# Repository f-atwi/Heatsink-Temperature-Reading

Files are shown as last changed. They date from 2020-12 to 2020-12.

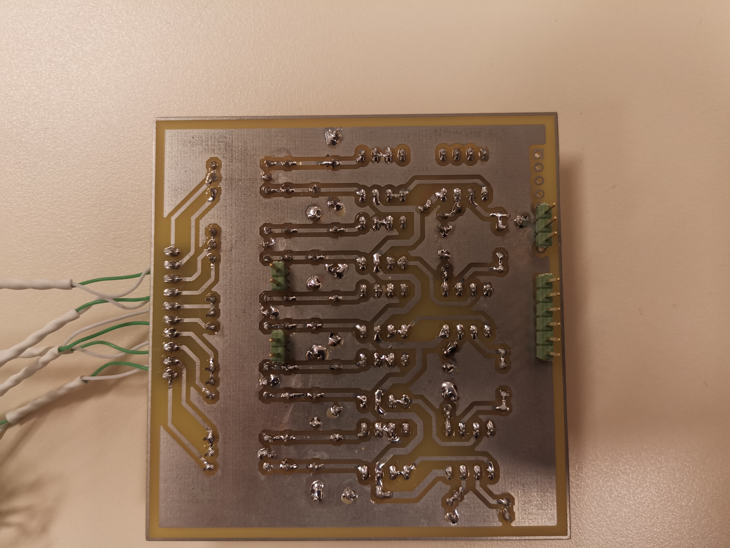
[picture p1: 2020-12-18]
PCB_Bottom.jpg

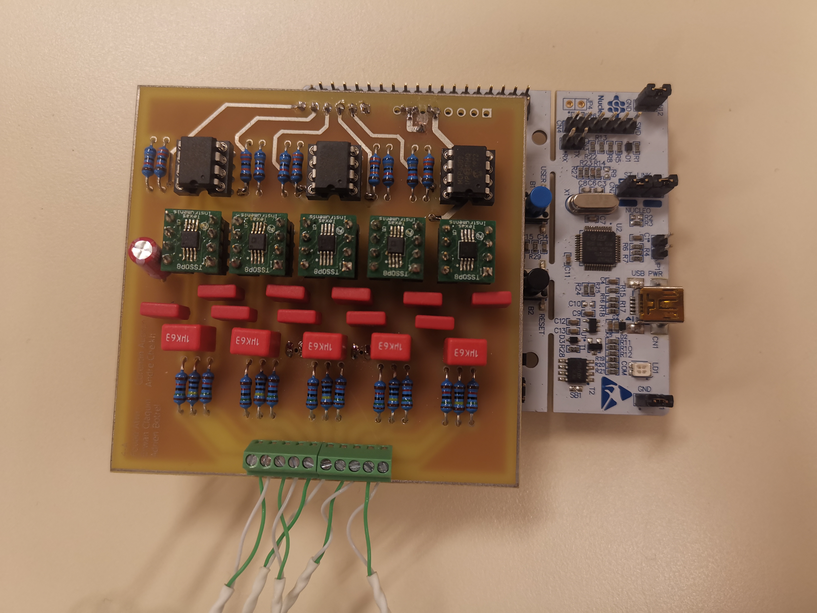
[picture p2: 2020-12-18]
PCB_Top.jpg

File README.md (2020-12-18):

# Heatsink_Temperature_Reading
A project to read temperature of a heatsink by 5 thermocouples and 3D visualize them on the computer.

The PCB design was made completely on Eagle. 
Custom packages for the AD8495 where created to make the board. The board was designed as a shield for the STM32 Nucleo F411RE and also compatible with Arduino boards. 
PDFs of the schematic and board as well as the PCB project files can be found.
The ciruit was designed to be powered completely by the Nucleo board. No external connections required.

The code for the STM32 Nucleo F411RE board was written on the STM32Cube IDE. 
The code initialized an ADC to read data from the designed shield, a DMA to transfer data from ADC to memory, and a UART to tranfer data to the PC.
The data read are also paired with a sensor ID for correct reading on the PC end.

Solidworks was used to model the heatsink. This model will be used by matlab to show temperatures as colors.

The Matlab code is where all the visualizing takes place.
Matlab takes the obj file of the model. 
It uses data received from UART to get the temperatures. The IDs transmitted with the temperatures helps pinpoint which sensor the data is from.
The data is hence displayed as color where blue is the coldest (minimum is 15°C) and red is the hottest (maximum 60°C).

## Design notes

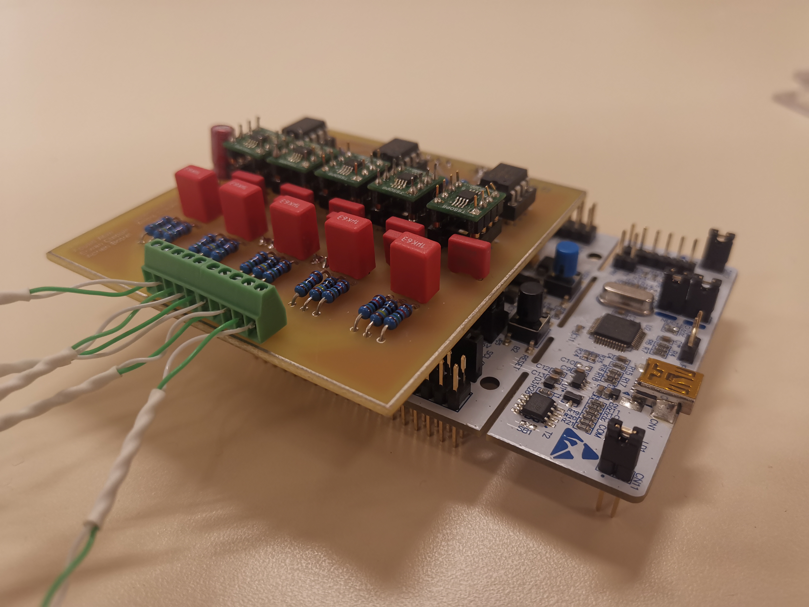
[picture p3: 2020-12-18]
PCB_Top_w_STM32.jpg

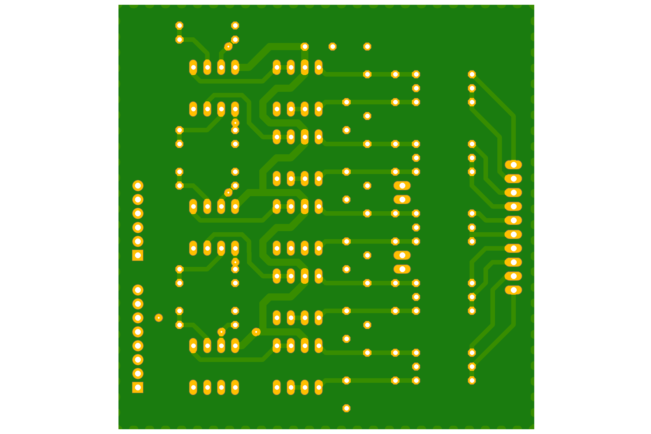
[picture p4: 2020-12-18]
Eagle_PCB_Project/PCB_Bottom_Visualize.png

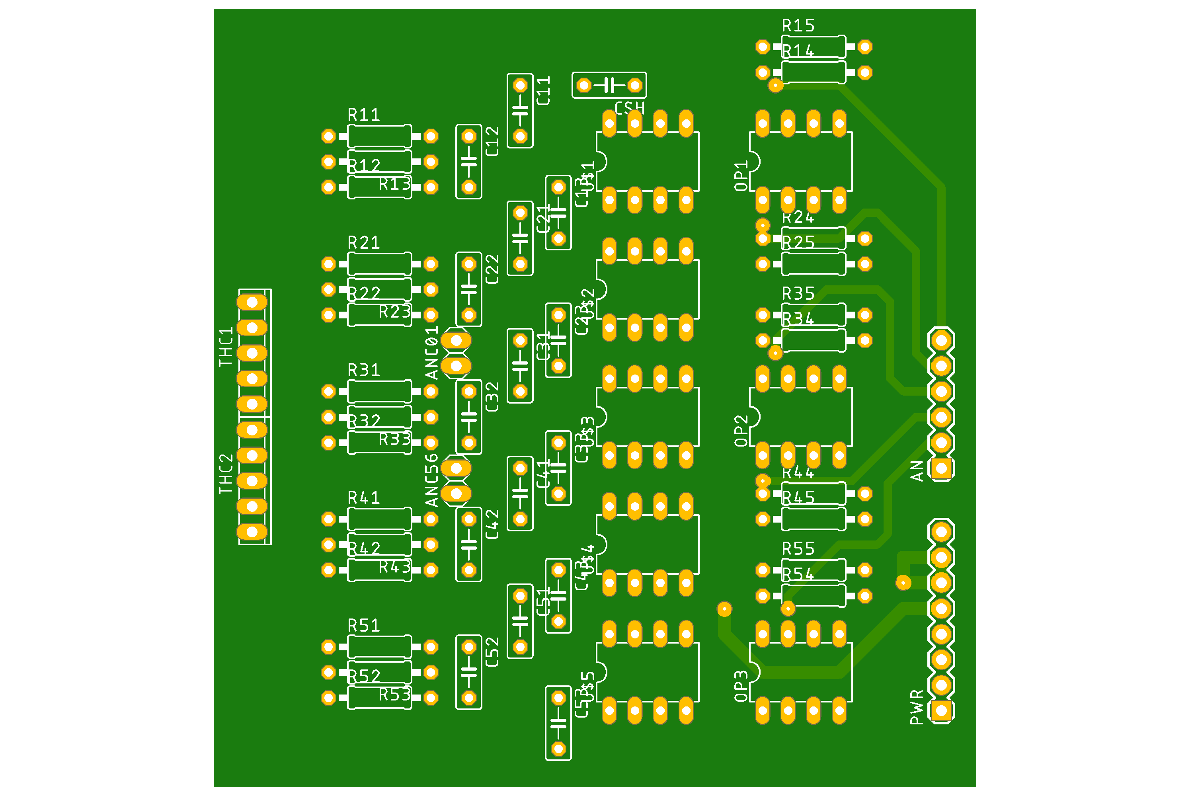
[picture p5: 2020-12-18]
Eagle_PCB_Project/PCB_Top_Visualize.png

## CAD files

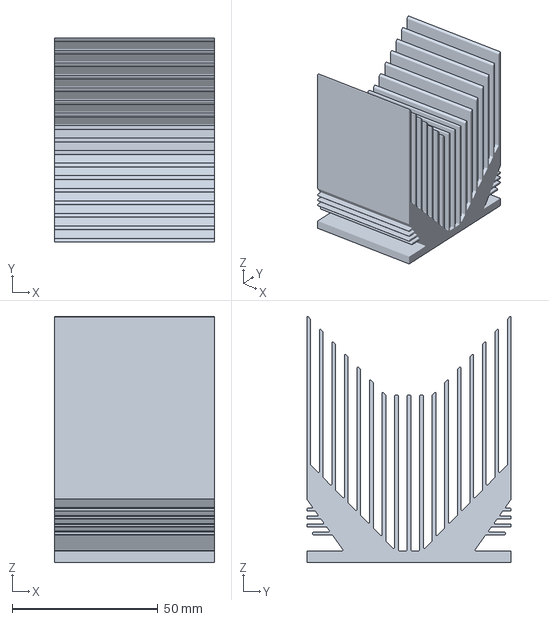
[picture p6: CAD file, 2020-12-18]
3D Model/Heatsink.3MF
55.0 x 70.1 x 84.3 mm

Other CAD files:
3D Model/Heatsink.obj

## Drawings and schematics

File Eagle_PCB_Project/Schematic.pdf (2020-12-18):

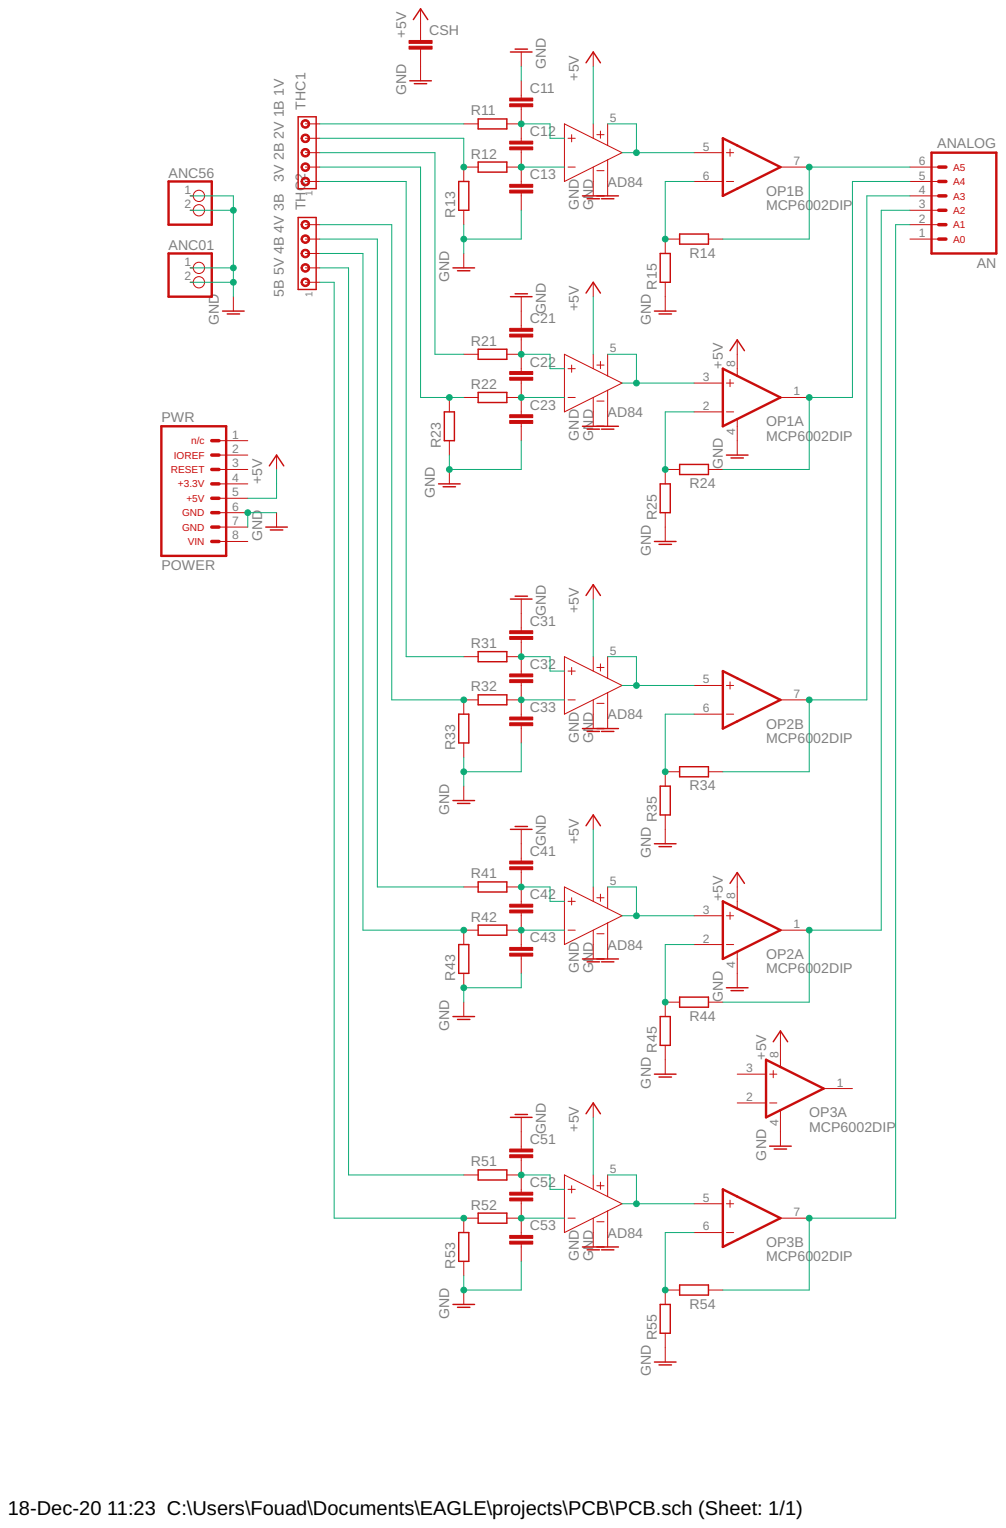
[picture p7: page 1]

GND GND GND GND GND

GND GND GND GND GND GND GND GND GND GND GND GND GND GND GND

18-Dec-20 11:23 C:\Users\Fouad\Documents\EAGLE\projects\PCB\PCB.sch (Sheet: 1/1)

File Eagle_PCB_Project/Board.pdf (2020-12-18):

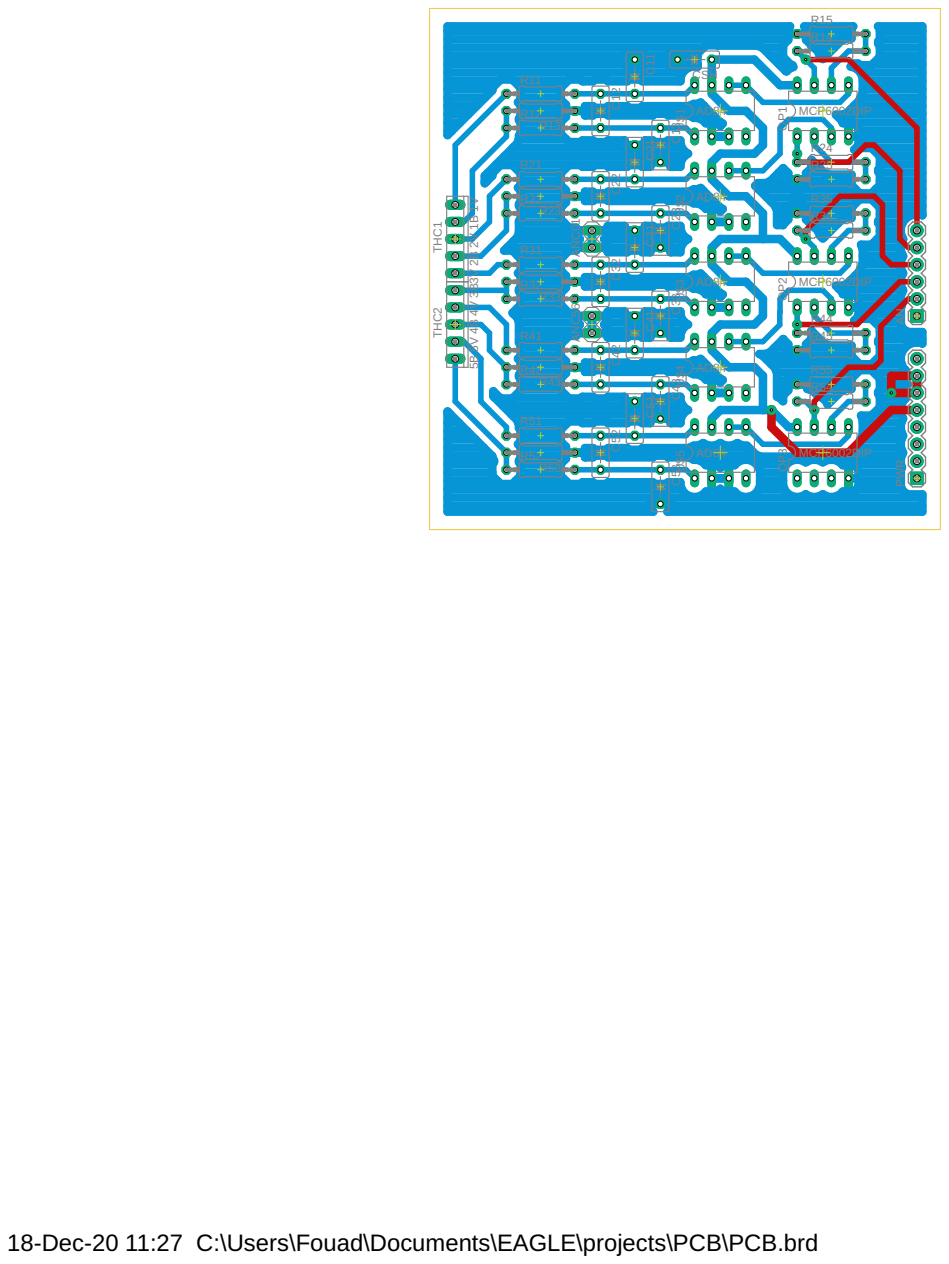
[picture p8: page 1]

18-Dec-20 11:27 C:\Users\Fouad\Documents\EAGLE\projects\PCB\PCB.brd

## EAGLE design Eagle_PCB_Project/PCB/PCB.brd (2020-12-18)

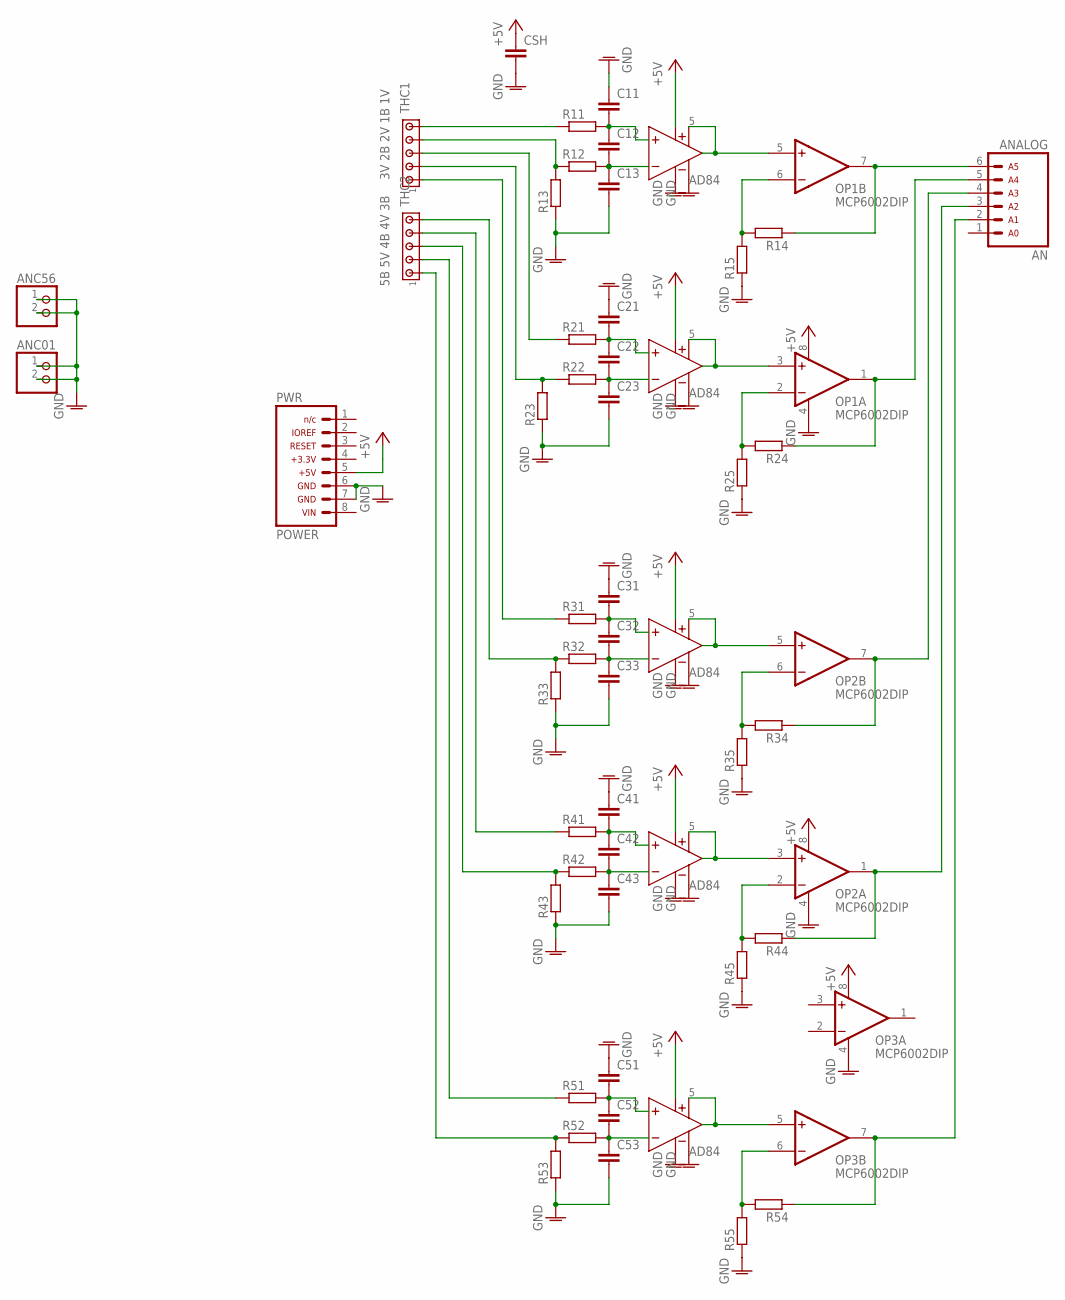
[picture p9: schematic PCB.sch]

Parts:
AN: ARDUINO_CONN-ANALOGSIP; CONN-1X06
ANC01, ANC56: PINHD-1X2; 1X02
C11, C12, C13, C21, C22, C23, C31, C32, C33, C41, C42, C43, C51, C52, C53: C-EU050-025X075; C050-025X075
CSH: C-EU050-025X075; C050-025X075
OP1, OP2, OP3: MCP6002DIP; DIP-8
PWR: ARDUINO_CONN-POWERSIP; CONN-1X08
R11, R12, R13, R14, R15, R21, R22, R23, R24, R25, R31, R32, R33, R34, R35, R41, R42, R43, R44, R45, R51, R52, R53, R54, R55: R-EU_0207/10; 0207/10
THC1: 3V 2B 2V 1B 1V; 10X05MTA
THC2: 5B 5V 4B 4V 3B; 10X05MTA
U$1, U$2, U$3, U$4, U$5: AD84; DIP-8

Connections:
+5V: CSH.1, OP1.8 (V+), OP2.8 (V+), OP3.8 (V+), PWR.5, U$1.7 (V+), U$2.7 (V+), U$3.7 (V+), U$4.7 (V+), U$5.7 (V+)
GNDA: ANC01.1, ANC01.2, ANC56.1, ANC56.2, C11.1, C13.2, C21.1, C23.2, C31.1, C33.2, C41.1, C43.2, C51.1, C53.2, CSH.2, OP1.4 (V-), OP2.4 (V-), OP3.4 (V-), PWR.6, PWR.7, R13.1, R15.1, R23.1, R25.1, R33.1, R35.1, R43.1, R45.1, R53.1, R55.1, U$1.2 (REF), U$1.3 (V-), U$2.2 (REF), U$2.3 (V-), U$3.2 (REF), U$3.3 (V-), U$4.2 (REF), U$4.3 (V-), U$5.2 (REF), U$5.3 (V-)
unnamed: OP1.5 (+IN), U$1.5 (SENS), U$1.6 (OUT)
unnamed: AN.6, OP1.7 (OUT), R14.1
unnamed: OP1.6 (-IN), R14.2, R15.2
unnamed: C11.2, C12.1, R11.2, U$1.8 (IN+)
unnamed: R12.1, R13.2, THC1.4
unnamed: C12.2, C13.1, R12.2, U$1.1 (IN-)
unnamed: R22.1, R23.2, THC1.2
unnamed: R32.1, R33.2, THC2.5
unnamed: OP1.2 (-IN), R24.2, R25.2
unnamed: C21.2, C22.1, R21.2, U$2.8 (IN+)
unnamed: C22.2, C23.1, R22.2, U$2.1 (IN-)
unnamed: AN.5, OP1.1 (OUT), R24.1
unnamed: OP1.3 (+IN), U$2.5 (SENS), U$2.6 (OUT)
unnamed: OP2.5 (+IN), U$3.5 (SENS), U$3.6 (OUT)
unnamed: OP2.6 (-IN), R34.2, R35.2
unnamed: C31.2, C32.1, R31.2, U$3.8 (IN+)
unnamed: C32.2, C33.1, R32.2, U$3.1 (IN-)
unnamed: AN.4, OP2.7 (OUT), R34.1
unnamed: R42.1, R43.2, THC2.3
unnamed: OP2.2 (-IN), R44.2, R45.2
unnamed: C41.2, C42.1, R41.2, U$4.8 (IN+)
unnamed: C42.2, C43.1, R42.2, U$4.1 (IN-)
unnamed: AN.3, OP2.1 (OUT), R44.1
unnamed: OP2.3 (+IN), U$4.5 (SENS), U$4.6 (OUT)
unnamed: R52.1, R53.2, THC2.1
unnamed: OP3.5 (+IN), U$5.5 (SENS), U$5.6 (OUT)
unnamed: OP3.6 (-IN), R54.2, R55.2
unnamed: C51.2, C52.1, R51.2, U$5.8 (IN+)
unnamed: C52.2, C53.1, R52.2, U$5.1 (IN-)
unnamed: AN.2, OP3.7 (OUT), R54.1
unnamed: R11.1, THC1.5
unnamed: R21.1, THC1.3
unnamed: R31.1, THC1.1
unnamed: R41.1, THC2.4
unnamed: R51.1, THC2.2

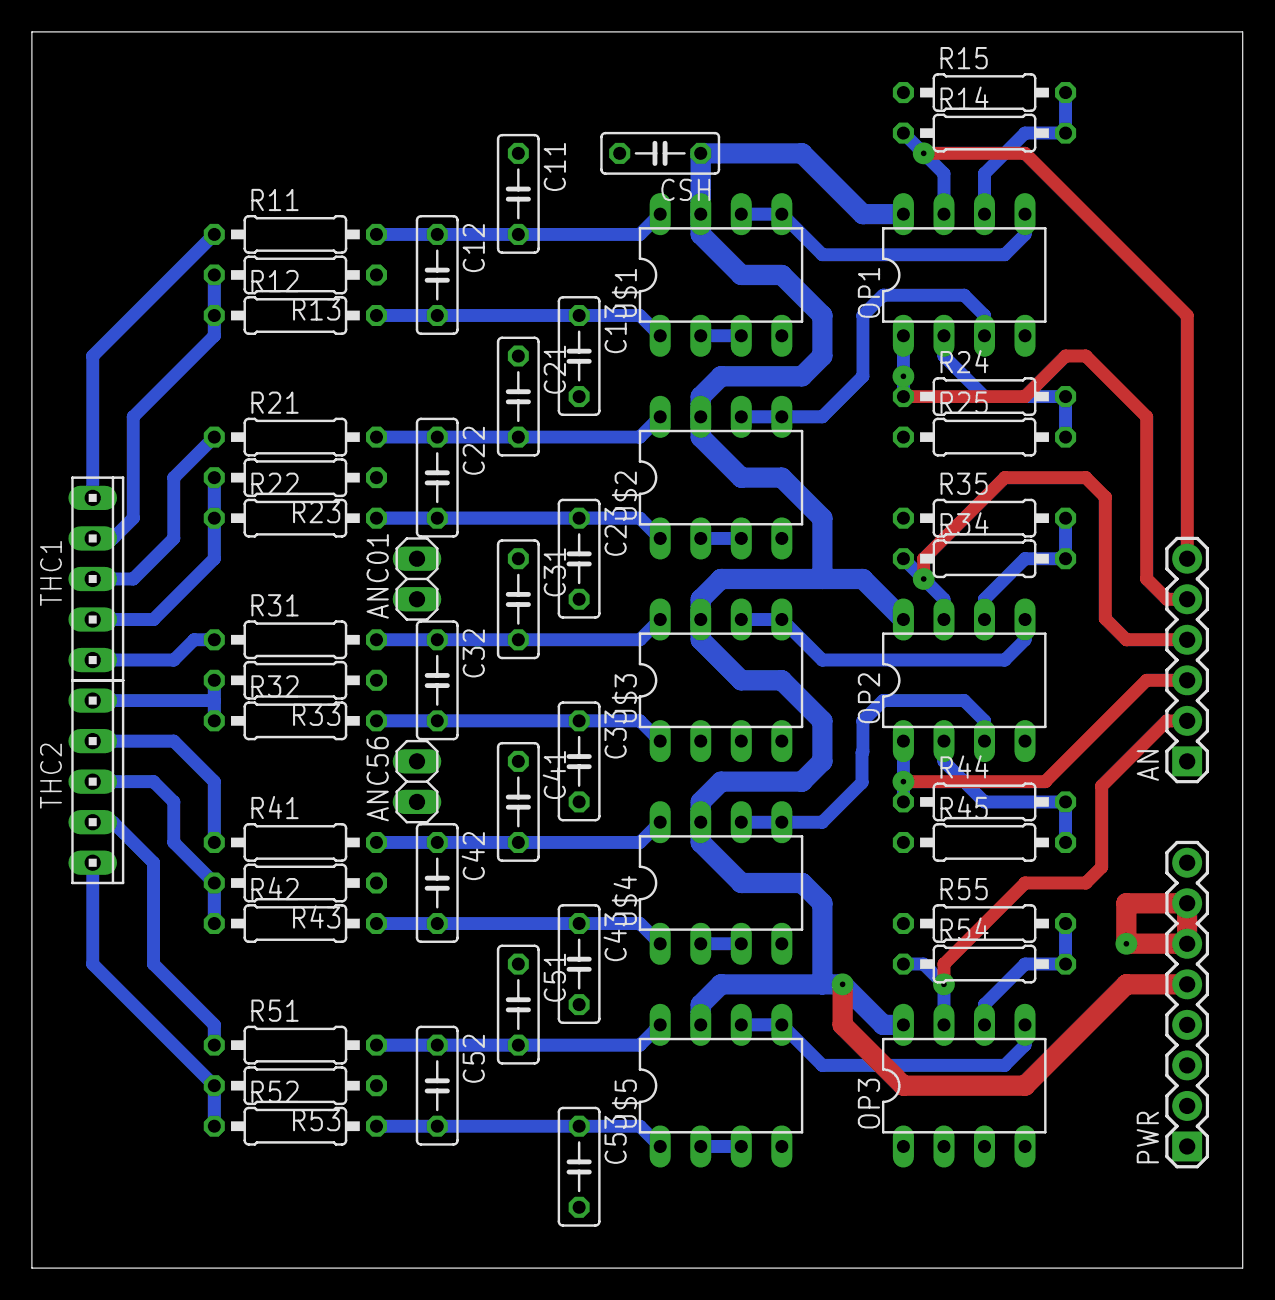
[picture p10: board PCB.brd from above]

Board: 2 copper layers, 75.9 x 77.5 mm, 55 parts (0 on the bottom side), 37 nets.

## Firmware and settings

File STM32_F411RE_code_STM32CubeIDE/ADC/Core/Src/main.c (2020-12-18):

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
/* Includes ------------------------------------------------------------------*/
#include "main.h"

/* USER CODE BEGIN Includes */
#include<string.h>
#include<stdio.h>
/* USER CODE END Includes */

ADC_HandleTypeDef hadc1;
DMA_HandleTypeDef hdma_adc1;

UART_HandleTypeDef huart2;

void SystemClock_Config(void);
static void MX_GPIO_Init(void);
static void MX_DMA_Init(void);
static void MX_USART2_UART_Init(void);
static void MX_ADC1_Init(void);
/* USER CODE BEGIN 0 */
uint16_t buffer[5];
/* USER CODE END 0 */

/**
  * @brief  The application entry point.
  * @retval int
  */
int main(void)
{
  /* MCU Configuration--------------------------------------------------------*/

  /* Reset of all peripherals, Initializes the Flash interface and the Systick. */
  HAL_Init();

  /* Configure the system clock */
  SystemClock_Config();

  /* Initialize all configured peripherals */
  MX_GPIO_Init();
  MX_DMA_Init();
  MX_USART2_UART_Init();
  MX_ADC1_Init();
  /* USER CODE BEGIN 2 */
  char msg[100];

  /* USER CODE END 2 */

  /* Infinite loop */
  /* USER CODE BEGIN WHILE */

  while (1)
  {
	  HAL_ADC_Start_DMA(&hadc1, buffer , 5);
	  HAL_ADC_PollForConversion(&hadc1, HAL_MAX_DELAY);
	  HAL_ADC_Stop_DMA(&hadc1);
	  HAL_Delay(1000);

	  for(int i=0;i<5;i++){
		  buffer[i]=(buffer[i] & 0x0FFF) +(((i+1)<<12)& 0xF000);
	  }
	  sprintf(msg,"%hu\r\n%hu\r\n%hu\r\n%hu\r\n%hu\r\n",buffer[0],buffer[1],buffer[2],buffer[3],buffer[4]);
	  HAL_UART_Transmit(&huart2, (uint8_t*)msg,strlen(msg), HAL_MAX_DELAY);

	  HAL_Delay(1000);

    /* USER CODE END WHILE */

    /* USER CODE BEGIN 3 */
  }
  /* USER CODE END 3 */
}

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


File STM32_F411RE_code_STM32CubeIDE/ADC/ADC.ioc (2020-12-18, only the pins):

Mcu.UserName=STM32F411RETx
PA1.Signal=ADCx_IN1
PA2.Signal=USART2_TX
PA3.Signal=USART2_RX
PA4.Signal=ADCx_IN4
PB0.Signal=ADCx_IN8
PC0.Signal=ADCx_IN10
PC1.Signal=ADCx_IN11
PC14-OSC32_IN.Signal=RCC_OSC32_IN
PC15-OSC32_OUT.Signal=RCC_OSC32_OUT

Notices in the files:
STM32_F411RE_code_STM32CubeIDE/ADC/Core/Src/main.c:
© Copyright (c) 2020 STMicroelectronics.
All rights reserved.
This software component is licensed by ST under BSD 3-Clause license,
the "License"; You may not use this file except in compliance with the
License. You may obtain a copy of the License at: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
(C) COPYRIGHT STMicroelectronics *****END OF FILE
